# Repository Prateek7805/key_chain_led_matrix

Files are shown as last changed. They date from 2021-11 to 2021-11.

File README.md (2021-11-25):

# keychain led matrix
This project aims to create a web interface for a custom made PCB for an 8x16 LED matrix display using ESP8266.
The PCB is portable and contains smd components, the project code is written using Embedded C++, HTML, Pure CSS and Vanilla JavaScript with fewer dependencies.

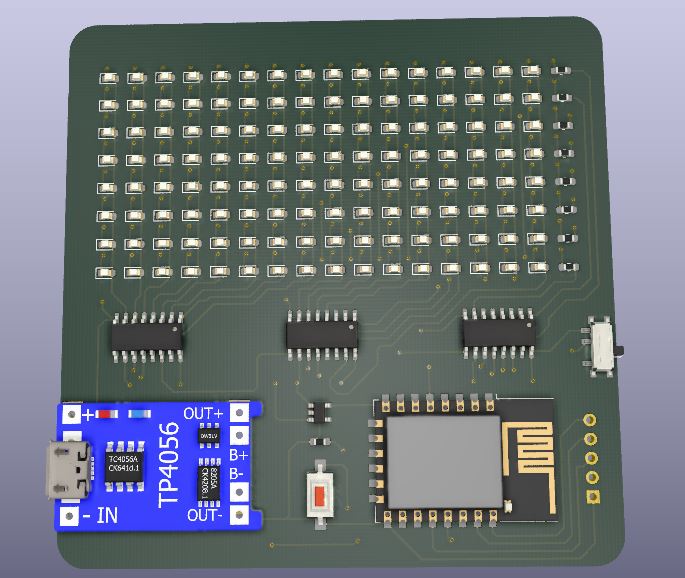
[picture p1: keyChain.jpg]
8x16 Display


[Demo](https://instagram.com/p/CPmjHNIFKIF/)

### Features: ###
* Pocket size PCB - smaller footprint using 0603 smd LEDs.
* Supports all printable characters in the ASCII table.
* Contains memory (Using SPIFFS).
* Web Interface to display words.
* Totally reprogrammable and hackable.
* Fewer components.
* battery operated and rechargable.
* Web Interface contains additional features to change from STA to AP, deepsleep, reset mcu etc.
* I have also built a webpage to create pixel art (8x8) however I also included the ASCII_Table.h containing all ASCII characters in 8 byte arrays.
* Brightness and scroll speed control.
* fast operation thanks to websockets.
* Uses Wifimanager hence can connect to any AP (Access Point) without reprogramming.

### The PCB is designed in KiCad ###

### Tool to make Pixel Art [click here](https://leddots.000webhostapp.com/)

### Dependencies ###
* [WiFiManager](https://github.com/tzapu/WiFiManager)
* [Websockets](https://github.com/Links2004/arduinoWebSockets)
* [FS Plugin](https://github.com/esp8266/arduino-esp8266fs-plugin/releases)

### Steps to make one: ###

#### Fabricating the PCB ####
* Download and Install KiCad.
* Open the 'keychain.pro' file from '/PCB Design' folder
* Edit the design if needed
* Generate the gerber and drill files
* Upload to the PCB manufacturers website

#### Uploading the code ####
* This requires an FTDI programmer or a nodemcu
* Follow the pinout below and connect the pins accordingly
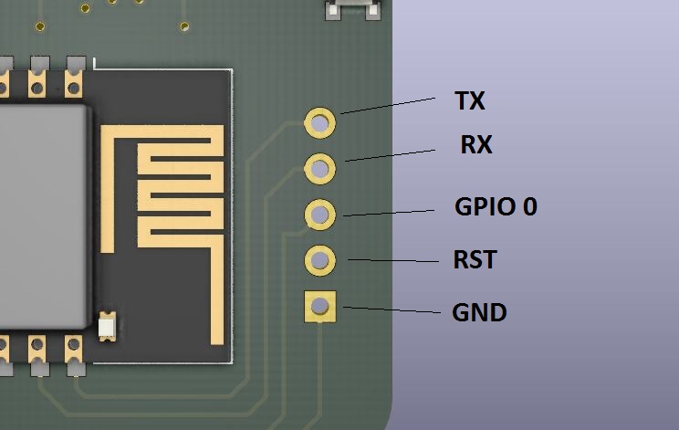
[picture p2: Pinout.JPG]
Pinout
  

* Download and Install Arduino IDE  
* Install ESP8266 board  
* [Install the SPIFFS upload plugin](https://randomnerdtutorials.com/install-esp8266-filesystem-uploader-arduino-ide/)  
* Open the keyChainMatrix-v6.ino  
* select the board to be ESP-12 and Flash size as 4MB(FS:2MB)  
* Select the appropriate COM PORT and click upload  
* Click tools > ESP8266 Sketch Data Upload  
* If you are new this I would recommend watching a tutorial on running a blick sketch on ESP8266  

#### Initial Setup ####
* Power on the card sized LED Matrix
* Since it uses WiFiManager WiFi credentials need to be stored in runtime.
* On you PC/smartphone open WiFi settings and connect to 'pocketMatrix' AP.
* It prompts a sign in or manually open a browser and go to '192.168.4.1/'.
* Now scan for the SSID (WiFi Name) or Enter the SSID and Password Manually.
* Now the ESP8266 resets and connect to the provided AP.

### Initial Run ###
* The LED matrix displays the Local IP on reboot or power on. 
* Connect your PC or smartphone to the same AP to which the LED matrix is connected.
* Open a browser and go to the IP address displayed by the LED matrix.
* The page displayed is the interface here
* You can enter any String in the Enter Text Input and click on submit
* The display will instantly display the entered text (Character limit: 1024)
* The range inputs can be used to change the speed and brightness as they fire onInput realtime results can be achived.
* You can rename or delete the strings data box below.
* You can power off the LED display using the On/Off button beside the Delete button however this only powers off the Display and **not the MCU and WiFi**.

### settings ###
* Open the web interface in a browser.
* Click the gear icon on the top right corner of the screen to open settings
* There are a number of cards each of which performs a function 
    * Wifi Mode - Used to change from connect to an AP (STA) to Start an AP (AP)
    * Factory Reset - Click the reset button and click 'Yes' to factory reset the display this will restore the original settings(Warning: The Data will be lost as it clears the SPIFFS)
    * Auto off - Sets an auto off timer
    * WiFi AP - Used to set SSID and Password for the AP mode
    * WiFi Power - clicking PowerDown turns the WIFI radio off However the text will still be displayed, just the wifi will be disabled
    * Reset - Clicking Reset MCU resets the ESP8266.
    * Deepsleep - Puts ESP8266 into deepSleep this can be used if the display needs to be turned off wirelessly however approx 20-50uA current is drawn.

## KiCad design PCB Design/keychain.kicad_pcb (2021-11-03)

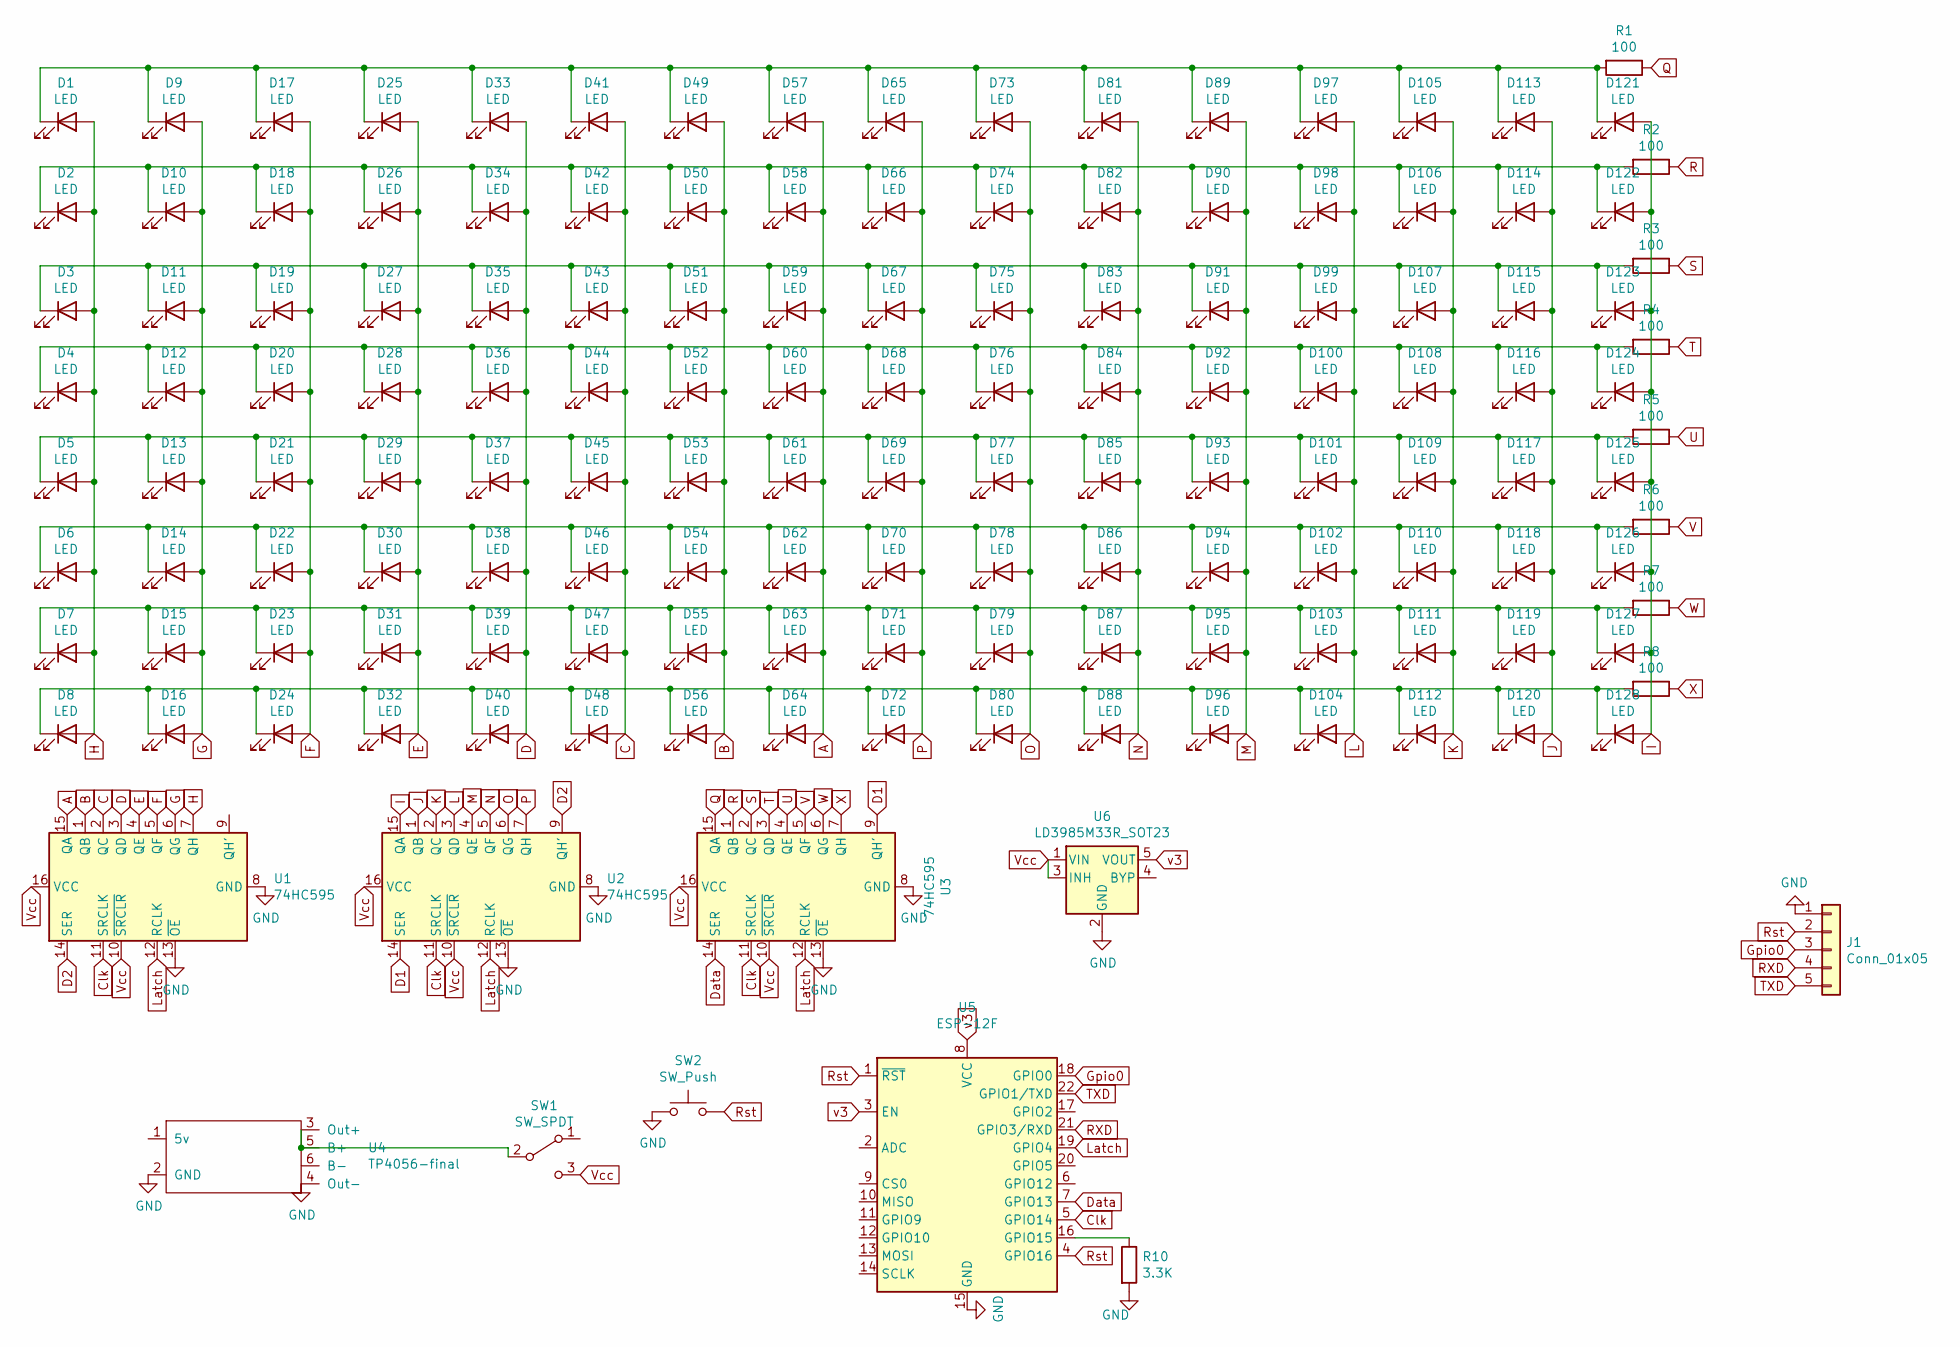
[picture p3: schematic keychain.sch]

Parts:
D1, D2, D3, D4, D5, D6, D7, D8, D9, D10, D11, D12, D13, D14, D15, D16, D17, D18, D19, D20, D21, D22, D23, D24, D25, D26, D27, D28, D29, D30, D31, D32, D33, D34, D35, D36, D37, D38, D39, D40, D41, D42, D43, D44, D45, D46, D47, D48, D49, D50, D51, D52, D53, D54, D55, D56, D57, D58, D59, D60, D61, D62, D63, D64, D65, D66, D67, D68, D69, D70, D71, D72, D73, D74, D75, D76, D77, D78, D79, D80, D81, D82, D83, D84, D85, D86, D87, D88, D89, D90, D91, D92, D93, D94, D95, D96, D97, D98, D99, D100, D101, D102, D103, D104, D105, D106, D107, D108, D109, D110, D111, D112, D113, D114, D115, D116, D117, D118, D119, D120, D121, D122, D123, D124, D125, D126, D127, D128: LED; LED_0603_1608Metric
J1: Conn_01x05; PinSocket_1x05_P2.54mm_Vertical
R1, R2, R3, R4, R5, R6, R7, R8: 100; R_0603_1608Metric_Pad1.05x0.95mm_HandSolder
R10: 3.3K; R_0603_1608Metric_Pad1.05x0.95mm_HandSolder
SW1: SW_SPDT; SW_SPDT_PCM12
SW2: SW_Push; SW_SPST_CK_RS282G05A3
U1, U2, U3: 74HC595; SOIC-16_3.9x9.9mm_P1.27mm
U4: TP4056-final; TP4056-18650
U5: ESP-12F; ESP-12E
U6: LD3985M33R_SOT23; SOT-23-5

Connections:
A: D57.2 (A), D58.2 (A), D59.2 (A), D60.2 (A), D61.2 (A), D62.2 (A), D63.2 (A), D64.2 (A), U1.15 (QA)
B: D49.2 (A), D50.2 (A), D51.2 (A), D52.2 (A), D53.2 (A), D54.2 (A), D55.2 (A), D56.2 (A), U1.1 (QB)
C: D41.2 (A), D42.2 (A), D43.2 (A), D44.2 (A), D45.2 (A), D46.2 (A), D47.2 (A), D48.2 (A), U1.2 (QC)
Clk: U1.11 (SRCLK), U2.11 (SRCLK), U3.11 (SRCLK), U5.5 (GPIO14)
D: D33.2 (A), D34.2 (A), D35.2 (A), D36.2 (A), D37.2 (A), D38.2 (A), D39.2 (A), D40.2 (A), U1.3 (QD)
D1: U2.14 (SER), U3.9 (QH')
D2: U1.14 (SER), U2.9 (QH')
Data: U3.14 (SER), U5.7 (GPIO13)
E: D25.2 (A), D26.2 (A), D27.2 (A), D28.2 (A), D29.2 (A), D30.2 (A), D31.2 (A), D32.2 (A), U1.4 (QE)
F: D17.2 (A), D18.2 (A), D19.2 (A), D20.2 (A), D21.2 (A), D22.2 (A), D23.2 (A), D24.2 (A), U1.5 (QF)
G: D9.2 (A), D10.2 (A), D11.2 (A), D12.2 (A), D13.2 (A), D14.2 (A), D15.2 (A), D16.2 (A), U1.6 (QG)
GND: J1.1, R10.2, SW2.1, U1.8 (GND), U1.13 (~OE), U2.8 (GND), U2.13 (~OE), U3.8 (GND), U3.13 (~OE), U4.2 (GND), U4.4 (Out-), U5.15 (GND), U6.2 (GND)
Gpio0: J1.3, U5.18 (GPIO0)
H: D1.2 (A), D2.2 (A), D3.2 (A), D4.2 (A), D5.2 (A), D6.2 (A), D7.2 (A), D8.2 (A), U1.7 (QH)
I: D121.2 (A), D122.2 (A), D123.2 (A), D124.2 (A), D125.2 (A), D126.2 (A), D127.2 (A), D128.2 (A), U2.15 (QA)
J: D113.2 (A), D114.2 (A), D115.2 (A), D116.2 (A), D117.2 (A), D118.2 (A), D119.2 (A), D120.2 (A), U2.1 (QB)
K: D105.2 (A), D106.2 (A), D107.2 (A), D108.2 (A), D109.2 (A), D110.2 (A), D111.2 (A), D112.2 (A), U2.2 (QC)
L: D97.2 (A), D98.2 (A), D99.2 (A), D100.2 (A), D101.2 (A), D102.2 (A), D103.2 (A), D104.2 (A), U2.3 (QD)
Latch: U1.12 (RCLK), U2.12 (RCLK), U3.12 (RCLK), U5.19 (GPIO4)
M: D89.2 (A), D90.2 (A), D91.2 (A), D92.2 (A), D93.2 (A), D94.2 (A), D95.2 (A), D96.2 (A), U2.4 (QE)
N: D81.2 (A), D82.2 (A), D83.2 (A), D84.2 (A), D85.2 (A), D86.2 (A), D87.2 (A), D88.2 (A), U2.5 (QF)
unnamed: D1.1 (K), D9.1 (K), D17.1 (K), D25.1 (K), D33.1 (K), D41.1 (K), D49.1 (K), D57.1 (K), D65.1 (K), D73.1 (K), D81.1 (K), D89.1 (K), D97.1 (K), D105.1 (K), D113.1 (K), D121.1 (K), R1.2
unnamed: D2.1 (K), D10.1 (K), D18.1 (K), D26.1 (K), D34.1 (K), D42.1 (K), D50.1 (K), D58.1 (K), D66.1 (K), D74.1 (K), D82.1 (K), D90.1 (K), D98.1 (K), D106.1 (K), D114.1 (K), D122.1 (K), R2.2
unnamed: D4.1 (K), D12.1 (K), D20.1 (K), D28.1 (K), D36.1 (K), D44.1 (K), D52.1 (K), D60.1 (K), D68.1 (K), D76.1 (K), D84.1 (K), D92.1 (K), D100.1 (K), D108.1 (K), D116.1 (K), D124.1 (K), R4.2
unnamed: D5.1 (K), D13.1 (K), D21.1 (K), D29.1 (K), D37.1 (K), D45.1 (K), D53.1 (K), D61.1 (K), D69.1 (K), D77.1 (K), D85.1 (K), D93.1 (K), D101.1 (K), D109.1 (K), D117.1 (K), D125.1 (K), R5.2
unnamed: D6.1 (K), D14.1 (K), D22.1 (K), D30.1 (K), D38.1 (K), D46.1 (K), D54.1 (K), D62.1 (K), D70.1 (K), D78.1 (K), D86.1 (K), D94.1 (K), D102.1 (K), D110.1 (K), D118.1 (K), D126.1 (K), R6.2
unnamed: D7.1 (K), D15.1 (K), D23.1 (K), D31.1 (K), D39.1 (K), D47.1 (K), D55.1 (K), D63.1 (K), D71.1 (K), D79.1 (K), D87.1 (K), D95.1 (K), D103.1 (K), D111.1 (K), D119.1 (K), D127.1 (K), R7.2
unnamed: D8.1 (K), D16.1 (K), D24.1 (K), D32.1 (K), D40.1 (K), D48.1 (K), D56.1 (K), D64.1 (K), D72.1 (K), D80.1 (K), D88.1 (K), D96.1 (K), D104.1 (K), D112.1 (K), D120.1 (K), D128.1 (K), R8.2
unnamed: D3.1 (K), D11.1 (K), D19.1 (K), D27.1 (K), D35.1 (K), D43.1 (K), D51.1 (K), D59.1 (K), D67.1 (K), D75.1 (K), D83.1 (K), D91.1 (K), D99.1 (K), D107.1 (K), D115.1 (K), D123.1 (K), R3.2
unnamed: R10.1, U5.16 (GPIO15)
unnamed: SW1.2 (B), U4.3 (Out+), U4.5 (B+)
O: D73.2 (A), D74.2 (A), D75.2 (A), D76.2 (A), D77.2 (A), D78.2 (A), D79.2 (A), D80.2 (A), U2.6 (QG)
P: D65.2 (A), D66.2 (A), D67.2 (A), D68.2 (A), D69.2 (A), D70.2 (A), D71.2 (A), D72.2 (A), U2.7 (QH)
Q: R1.1, U3.15 (QA)
R: R2.1, U3.1 (QB)
RXD: J1.4, U5.21 (GPIO3/RXD)
Rst: J1.2, SW2.2, U5.1 (~RST), U5.4 (GPIO16)
S: R3.1, U3.2 (QC)
T: R4.1, U3.3 (QD)
TXD: J1.5, U5.22 (GPIO1/TXD)
U: R5.1, U3.4 (QE)
V: R6.1, U3.5 (QF)
Vcc: SW1.3 (C), U1.10 (~SRCLR), U1.16 (VCC), U2.10 (~SRCLR), U2.16 (VCC), U3.10 (~SRCLR), U3.16 (VCC), U6.1 (VIN), U6.3 (INH)
W: R7.1, U3.6 (QG)
X: R8.1, U3.7 (QH)
v3: U5.3 (EN), U5.8 (VCC), U6.5 (VOUT)

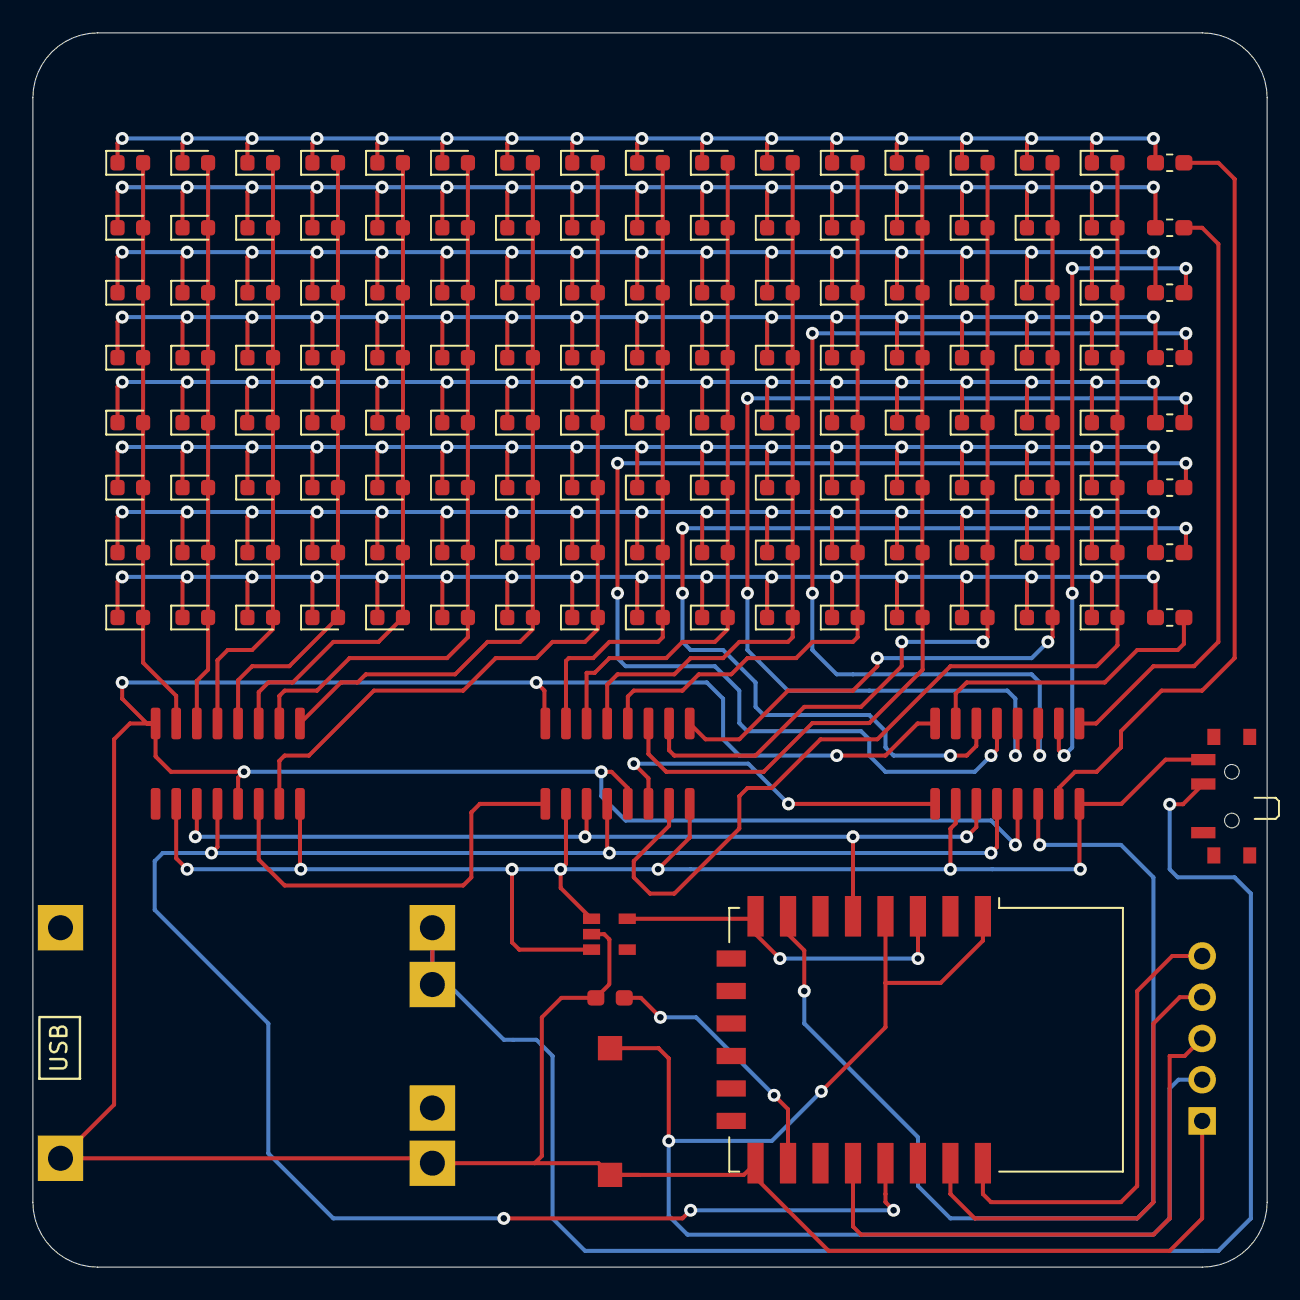
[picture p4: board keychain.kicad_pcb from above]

Board: 2 copper layers, 76.0 x 76.0 mm, 146 parts (0 on the bottom side), 46 nets.

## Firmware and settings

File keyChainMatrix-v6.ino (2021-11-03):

#include<ESP8266WiFi.h>
#include<WiFiManager.h>
#include<ESP8266WebServer.h>
#include<FS.h>
#include<WebSocketsServer.h>

#include<SPI.h>
#include "ASCII_Table.h"
static const uint8_t COLSIZE = 16;
static const uint8_t MAXBRIGHT = 200;
static const uint16_t MAXSPEED = 1000;
uint8_t DATA = 13;
uint8_t CLK = 14;
uint8_t LATCH = 4;

String NAME = "AB  ";
uint16_t currentInd = 0;

uint8_t BUFFER[COLSIZE];
bool changeOfName = false;

uint16_t SPEED = 500;
uint16_t BRIGHT = 300;
String CONTENT = "/data";
String CONTENT2 = "/dat";

bool WM = 0;
unsigned long AO = 0;
String AP = "pocketMatrix,pocketMatrix";
String AP_SSID = "";
String AP_PASS = "";

unsigned long WO = 0;

unsigned long A_time = 0;
unsigned long WO_time = 0;

String WO_SSID = "";
String WO_PASS = "";

bool dispOff = true;
IPAddress apIP(192, 168, 4,1);  
IPAddress gateway(192, 168,12, 7);
IPAddress subnet(255, 255, 255, 0); 

ESP8266WebServer server(80);
WebSocketsServer webSocket = WebSocketsServer(81);
WiFiManager wifimanager;

void returnOK() {
  server.send(200, "text/plain", "");
}

void handleOtherFiles(){
  if(checkInFS(server.uri())){
    return;
  }
  server.send(404,"text.plain", "please restart the display");
  
}

void createCurr(){  
  File file = SPIFFS.open("/curr.txt", "w");
  file.print("Test  \n880\n150\n/data.txt\n/dat.txt\n0\n0\npocketMatrix,\n");
  file.close();
}

bool checkInFS(String path){
  
  feedAutoOff();
  String dataType = "text/plain";
  if(path.endsWith("/") || path.endsWith(".html")){
    dataType = "text/html";
    path = "/index.html";
  }else if(path.endsWith(".css")){
    dataType = "text/css";
    path = "/styles.css";
  }else if(path.endsWith(".js")){
    dataType = "application/js";
    path = "/script.js";
  }else{
    return false;
  }
  
  File file = SPIFFS.open(path, "r");
  if(!file)
    return false;
  server.streamFile(file, dataType);
  file.close();
  return true;
}

void formatName(String ARG){
  NAME = ARG;
  NAME += "  ";
  currentInd = 0;
  updateCurr();
  changeOfName = true;
  clearBuffer();
}

void inputText(){
  formatName(server.arg(0));
  File fileAppend = SPIFFS.open(CONTENT, "a");
  fileAppend.println(server.arg(0));
  fileAppend.close();
  returnOK();
  feedAutoOff();
}

void updateCurr(){
  File file = SPIFFS.open("/curr.txt", "w");
  String toWrite = NAME + '\n' + String(SPEED) + '\n' + String(BRIGHT) + '\n' + CONTENT + '\n' + CONTENT2 + '\n' + String(WM) + '\n' + String(AO) + '\n' + AP + '\n';
  Serial.println(toWrite);
  file.print(toWrite);
  file.close();
  feedAutoOff();
}

void sendJSON(){
  server.setContentLength(CONTENT_LENGTH_UNKNOWN);
  server.send(200, "text/json", "");
  server.sendContent("[");
  File file = SPIFFS.open(CONTENT, "r");
  uint8_t removeSpace = (COLSIZE/8);
  while(file.available()){
    server.sendContent("\"");
    String buttonName = file.readStringUntil('\n');
    server.sendContent(buttonName.substring(0, buttonName.length()-1)); // remove the \n
    server.sendContent("\",");
  }
  server.sendContent("]");
  server.sendContent("");
  file.close();
  feedAutoOff();
}

String IPToString(const IPAddress& ipAddress)
{
    return String(ipAddress[0]) + String(".") +
           String(ipAddress[1]) + String(".") +
           String(ipAddress[2]) + String(".") +
           String(ipAddress[3]);
}

void displayIP(uint16_t s, uint16_t b){
  SPEED = (MAXSPEED * 0.98);
  BRIGHT = MAXBRIGHT;
  scroll(IPToString(WiFi.localIP()) + "  ");
  SPEED = s;
  BRIGHT = b;
}

void deleteTXT(){
  uint32_t ind = server.arg(0).toInt();
  uint32_t cur = server.arg(1).toInt();
  Serial.println(server.arg(0));
  uint32_t count = 0;
  File file = SPIFFS.open(CONTENT2, "w");
  file.print("");
  file.close();
  
  file = SPIFFS.open(CONTENT, "r");
  File file2 = SPIFFS.open(CONTENT2, "a");
  while(file.available()){
    String temp = file.readStringUntil('\n');
    uint16_t len = temp.length();
    temp = temp.substring(0,len-1);
    if(count == cur)
      formatName(temp);
    if(count != ind)
      file2.println(temp);
    ++count;
  }
  file.close();
  file2.close();
  String temp = CONTENT;
  CONTENT = CONTENT2;
  CONTENT2 = temp;
  updateCurr();
  feedAutoOff();
  returnOK();  
}
void renameTXT(){
  uint32_t ind = server.arg(0).toInt();
  String txt = server.arg(1);
  uint8_t FL = server.arg(2).toInt();
  uint32_t count = 0;
  File file = SPIFFS.open(CONTENT2, "w");
  file.print("");
  file.close();
  file = SPIFFS.open(CONTENT, "r");
  File file2 = SPIFFS.open(CONTENT2, "a");
  while(file.available()){
    String temp = file.readStringUntil('\n');
    uint16_t len = temp.length();
    temp = temp.substring(0,len-1);
    if(count != ind){
      file2.println(temp);
    }
    else{
      file2.println(txt);
      if(FL) formatName(txt);
    }
    ++count;
  }
  file.close();
  file2.close();
  String temp = CONTENT;
  CONTENT = CONTENT2;
  CONTENT2 = temp;
  updateCurr();
  feedAutoOff();
  returnOK();  
}

void initFlags(){
  File file = SPIFFS.open("/curr.txt", "r");
  NAME = file.readStringUntil('\n');
  SPEED = file.readStringUntil('\n').toInt();
  BRIGHT = file.readStringUntil('\n').toInt();
  CONTENT = file.readStringUntil('\n');
  CONTENT2 = file.readStringUntil('\n');
  WM = (bool)file.readStringUntil('\n').toInt();
  AO = file.readStringUntil('\n').toInt();
  AP = file.readStringUntil('\n');
  
  AP_SSID = AP.substring(0, AP.indexOf(','));
  AP_PASS = AP.substring(AP.indexOf(',')+1);
  
  Serial.println(AP_SSID);
  Serial.println(AP_PASS);
  file.close();
  changeOfName = true;
}
void setup() {
  Serial.begin(115200);
  SPIFFS.begin();
  if(!SPIFFS.exists("/curr.txt")){
    createCurr();
  }
  initFlags();
  

  Serial.println(CONTENT);
  Serial.println(CONTENT2);
  pinMode(DATA, OUTPUT);
  pinMode(CLK, OUTPUT);
  pinMode(LATCH, OUTPUT);
  SPI.begin();
  mprint(0,0,0xFF); //clear Display
  if(!WM)
    wifimanager.autoConnect(AP_SSID.c_str());
  else{
    WiFi.config(apIP, gateway, subnet);
    WiFi.mode(WIFI_AP);
    WiFi.disconnect();
    delay(100);
        //changing softAP config and starting the Start AP
    WiFi.softAPConfig(apIP, gateway, subnet);
    WiFi.softAP(AP_SSID.c_str(), AP_PASS.c_str());
  }
  server.on("/name", HTTP_GET, [](){
      server.send(200, "text/json", "[\""+NAME+"\", \""+String(SPEED)+"\", \""+String(BRIGHT)+"\",\""+"WM"+String(WM)+"\","+AO+"]");
    });
  server.on("/init", HTTP_GET, sendJSON);
  server.on("/input", HTTP_GET, inputText);
  server.on("/exist", HTTP_GET, [](){
    formatName(server.arg(0));
    returnOK();
  });
  server.on("/curr", HTTP_GET, [](){
    updateCurr();
    returnOK();
  });
  server.on("/del", HTTP_GET, deleteTXT);
  server.on("/rn", HTTP_GET, renameTXT);
  server.on("/off", HTTP_GET, [](){
    dispOff = (bool)server.arg(0).toInt();
    mprint(0,0,0xFF);
    changeOfName = true;
    returnOK();
  });
  server.onNotFound(handleOtherFiles);
  server.begin();
  webSocket.begin();
  webSocket.onEvent(socketHandle);
  
  displayIP(SPEED, BRIGHT);
  feedAutoOff();
}
void feedAutoOff(){
  A_time = millis();
}
void AutoOff(){
  if(AO!=0)
    if(millis() - A_time > AO){
      clearBuffer();
      ESP.deepSleep(0);
    }
}
void WifiOff(){
  Serial.println(WO);
  if(WO != 0){
    if(millis() - WO_time  > WO){
      WiFi.forceSleepWake();
        if(!WM){
         WiFi.begin(WO_SSID, WO_PASS);
         while(WiFi.status() != WL_CONNECTED){
            scroll(NAME);
         }
        }else{
          WiFi.config(apIP, gateway, subnet);
          WiFi.mode(WIFI_AP);
          WiFi.disconnect();
          delay(80);
          //changing softAP config and starting the Start AP
          WiFi.softAPConfig(apIP, gateway, subnet);
          WiFi.softAP(AP_SSID.c_str(), AP_PASS.c_str());
        }
      WO = 0;
    }
  }
}
void loop() {
  if(dispOff)
    scroll(NAME);
  
  AutoOff();
  WifiOff();
  server.handleClient();
  webSocket.loop();
}

void latch(){
  delayMicroseconds(10);
  digitalWrite(LATCH, HIGH);
  delayMicroseconds(10);
  digitalWrite(LATCH, LOW);
}

uint8_t getNextCol(String txt, uint32_t * len){  
  uint8_t col;
  
  while(1){
    uint16_t row = *(len)>>3; // /8
    col = ASCIIArray[(int)txt[row] - 32][*len%8];
    
    if(txt[row] != ' '){
      if(currentInd != row){
        
        if(col != 0){
          --(*len);
          currentInd = row;
          return 0;
        }else{
          ++(*len);
        }
      }else{
        if(col == 0){
          ++(*len);
        }else{
          return col;
        }
      }
    }else{
      return col;
    }
  }
}

void scroll(String txt){
  currentInd = 0;
  clearBuffer();
  changeOfName = false;
  uint32_t txtSize = txt.length()*8; 
  for(uint32_t len = 0; len<txtSize; ++len){  
      for(int i=0; i<(1002 - SPEED); ++i){
          for(int row=0; row<COLSIZE; ++row){
            server.handleClient();
            webSocket.loop();
            if(changeOfName) break;
            uint32_t col = (1<<(COLSIZE - (row+1)));
            if(BRIGHT > 0 && BRIGHT < MAXBRIGHT){
              mprint((col>>8)&0xFF,col&0xFF,~BUFFER[row]);
              delayMicroseconds(BRIGHT);
              mprint(0,0,0xFF); 
              delayMicroseconds(MAXBRIGHT - BRIGHT);
            }else if(BRIGHT >= MAXBRIGHT){
              mprint((col>>8)&0xFF,col&0xFF,~BUFFER[row]);
              delayMicroseconds(BRIGHT); 
            }else{
              mprint(0,0,0xFF);
            }
          }
          if(changeOfName) break;
      }
      wdt_reset();
      if(changeOfName) break;
      for(uint32_t i = 0; i<COLSIZE-1; ++i) BUFFER[i] = BUFFER[i+1];
      BUFFER[COLSIZE - 1] =  getNextCol(txt, &len);
   }
 }

void mprint(byte col1, byte col2, byte row){
  SPI.beginTransaction(SPISettings(1000000, MSBFIRST, SPI_MODE0));
  SPI.transfer(col1);
  SPI.transfer(col2);
  SPI.transfer(row);
  latch();
  SPI.endTransaction();
}

void clearBuffer(){
  for(int i = 0; i<COLSIZE; ++i) BUFFER[i] = 0x0;
}

void socketHandle(uint8_t num, WStype_t type, uint8_t * payload, size_t length){
  if(type == WStype_TEXT){
    switch(payload[0]){
      case 's': {
                  SPEED = (uint16_t) strtol((const char *)&payload[1], NULL, 10);
                  break;
                  }
      case 'b': {
                  BRIGHT = (uint16_t) strtol((const char *)&payload[1], NULL, 10);
                  break;
                }
      case 'W':{
                  switch(payload[1]){
                    case 'M':{
                      WM = (bool)(payload[2] - 48);
                      break;
                    }
                    case 'P':{
                      AP = String((char *)&payload[2]);
                      updateCurr();
                      AP_SSID = AP.substring(0, AP.indexOf(','));
                      AP_PASS = AP.substring(AP.indexOf(',')+1);
                      break;
                    }
                    case 'O':{
                      WO = String((const char *)&payload[2]).toInt()*60000;
                      
                      WO_SSID = wifimanager.getSSID();
                      WO_PASS = wifimanager.getPassword();
                      WiFi.persistent(false);
                      WiFi.mode(WIFI_OFF);      
                      WiFi.disconnect();          
                      WiFi.persistent(true);
                      WiFi.forceSleepBegin();
                      delay(10);
                      WO_time = millis();
                      break;
                    }
                  }
                }
      case 'A':{
                  AO = String((const char *)&payload[1]).toInt()*60000;
                  updateCurr();
                  Serial.println(AO);
                  break;
               }
      case 'R':{
                  switch(payload[1]){
                    case 'D':{
                      createCurr();
                      File fileAppend = SPIFFS.open("/data.txt", "w");
                      fileAppend.println("Test");
                      fileAppend.close();
                      initFlags();
                      break;
                    }
                    case 'S':{
                      switch(payload[2]){
                        case 'R':{
                          mprint(0,0,0xFF);
                          ESP.reset();
                        }
                        case 'D':{
                          uint32_t t= String((const char *)&payload[3]).toInt();
                          ESP.deepSleep(t);
                        }
                      }
                      break;  
                    }
                  }
               }
    }
    feedAutoOff();
    Serial.println(String((char *)&payload[0]));
  }
}

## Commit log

2021-11-03 Added KiCad files
    [keychain.kicad_pcb, keychain.sch]
2021-11-03 Added Gerbers
    [keychain-B_Cu.gbl, keychain-B_Mask.gbs, keychain-B_Paste.gbp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]
